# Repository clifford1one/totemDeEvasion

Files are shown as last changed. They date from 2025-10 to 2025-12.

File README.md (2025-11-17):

# totemDeEvasion

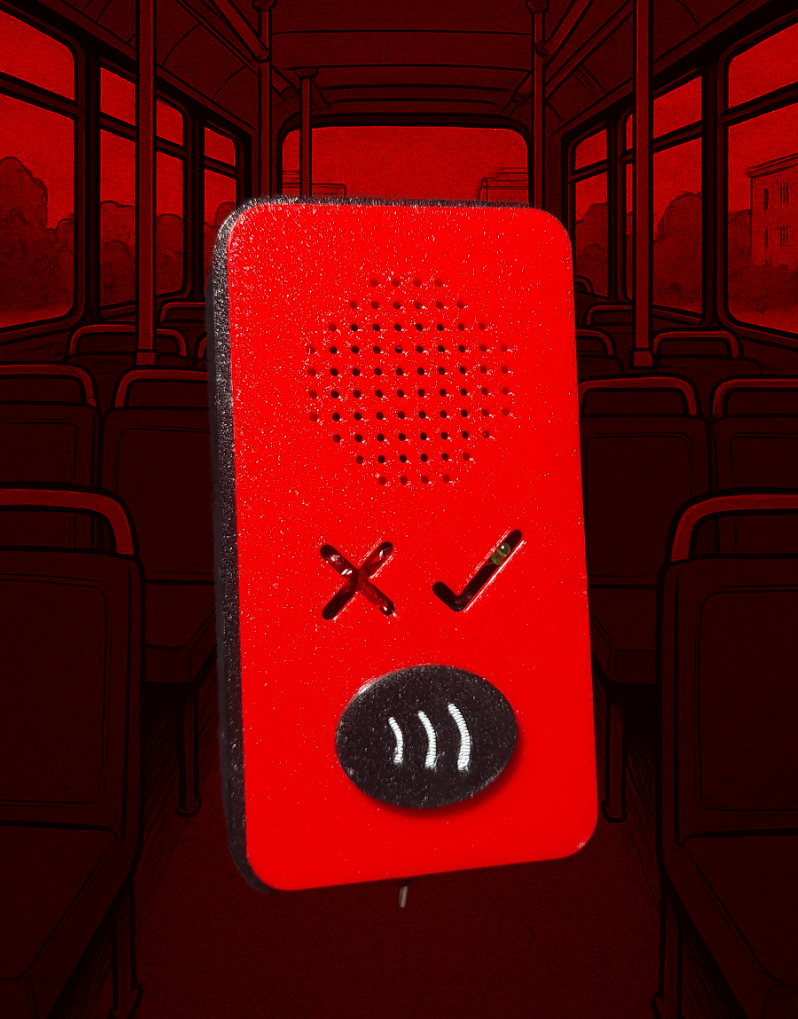
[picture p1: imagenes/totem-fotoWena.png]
imagen de presentación del totem


proyecto diseñado y fabricado por santiagoClifford en el marco de Halloween 2025. Consiste en la personificación de un ente imaginario, que representa el proceso de pagar el pasaje al subirse a las micros del sistema red.

## especificaciones

### Bill of Materials

|  | nombre | cantidad | lin compra | precio unidad(CLP) | precio item |
|---|---|---|---|---|---|
| interruptor | MTS-102 | 1 | https://afel.cl/products/interruptor-mts-102-3-pines | $400 | $400 |
| parlante | Mini Parlante Altavoz | 1 | https://afel.cl/products/mini-parlante-altavoz-de-3w | $3.000 | $3.000 |
| modulo mp3 | DFPlayer mini | 1 | https://afel.cl/products/modulo-reproductor-mp3-dfplayer-mini | $2.990 | $2.990 |
| micro sd | micro SD 16gb  | 1 | https://lapizlopez.cl/product/tarjeta-micro-sd-16gb-sdhc-cl10/ | $5.990 | $5.990 |
| lector NFC | RFID RC522 | 1 | https://afel.cl/products/lector-rfid-rc522 | $3.990 | $3.990 |
| mini broto | Mini protoboard | 1 | https://afel.cl/products/mini-protoboard-170-puntos | $990 | $990 |
| placa arduino compatible (yo usé UNO R4 Mínima) | Arduino Nano V3.0 CH340 | 1 | https://hubot.cl/producto/arduino-nano-atmega168-3-0v/ | $4.900 | $4.900 |
| cable alimentación | tipo-C a tipo-C | 1 | https://hubot.cl/producto/cable-tipo-c-a-tipo-c-para-carga-y-transmision-de-datos-30-cm-sku-4097/ | $990 | $990 |
| cables | Macho-Hembra | 1 | https://afel.cl/products/pack-20-cables-de-conexion-macho-hembra | $1.000 | $1.000 |
| cables | cable unifiliar | 20cm | https://mcielectronics.cl/shop/product/cable-para-protoboard-gris-sparkfun-10446 | $4.990 | $132 |
| led rojo | diodo led 5mm  | 2 | https://afel.cl/products/diodo-led-5mm-ultrabrillante-rojo | $70 | $140 |
| led verde | diodo led 5mm | 2 | https://afel.cl/products/diodo-led-5mm-ultrabrillante-verde?_pos=17&_sid=8cc70765c&_ss=r | $70 | $140 |
| filamento rojo | petg artillery | 25g | https://afel.cl/products/filamento-petg-rojo-artillery-1-75mm-1kg | $10.000 | $250 |
| filamento negro | pet-g artillery | 85g | https://afel.cl/products/filamento-petg-negro-artillery-1-75mm-1kg | $10.000 | $850 |
| cautín | MK0376 | 1 | https://www.mercadolibre.cl/cautin-tipo-lapiz-para-soldar-40-watts-makawa-mk-0376/p/MLC24329921 | $3.200 | $3.200 |
| estaño | Rollo soldadura | 2g | https://mcielectronics.cl/shop/product/rollo-soldadura-de-estano-1-0mm-30g/ | $3.000 | $200 |
| resistencias | 1k | 4 |  |  |  |
| resistencias | 10k | 1 |  |  |  |
| TOTAL |  |  |  |  |  |

### piezas impresas en 3D

| pieza | color | gramos |
|---|---|---|
| face | rojo | 24g |
| sostenNfc | rojo | 0.4g |
| midBod | negro | 50g |
| back | negro | 22g |
| spkrCap | negro | 6.2g |
| nfcCap | negro | 3g |
| lamp | negro | 2g |
| total | 2, 5 | 25g, 85g |

### cableado

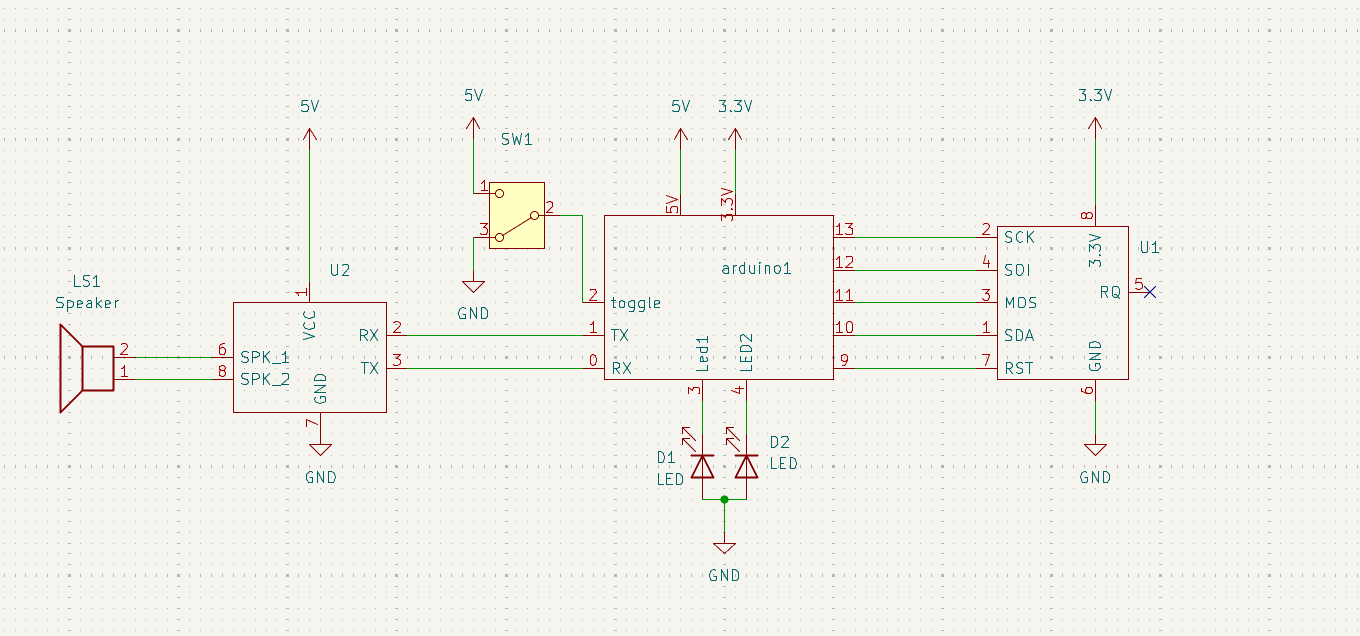
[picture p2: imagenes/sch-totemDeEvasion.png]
esquemático del cableado


esquemático hecho en kicad. Los símbolos del módulo MP3, del lector NFC y del arduino fueron hechos por mí, usando la herramienta de edición de símbolos de kicad.

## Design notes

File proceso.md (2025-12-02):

# fabricación robot y unión de partes

## proceso

este paso, viene después de entender el funcionaiento, por separado, del sensor nfc, y el toggle. 

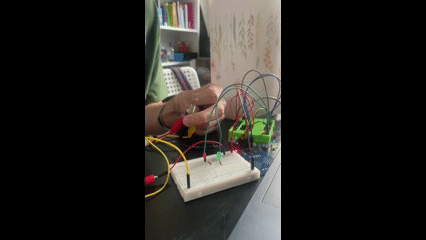
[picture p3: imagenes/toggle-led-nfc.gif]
gif del funcionamiento


armé el circuito para que, cuanod se sense un nfc, se mande un output de una LED, este output varía según el estado del toggle.

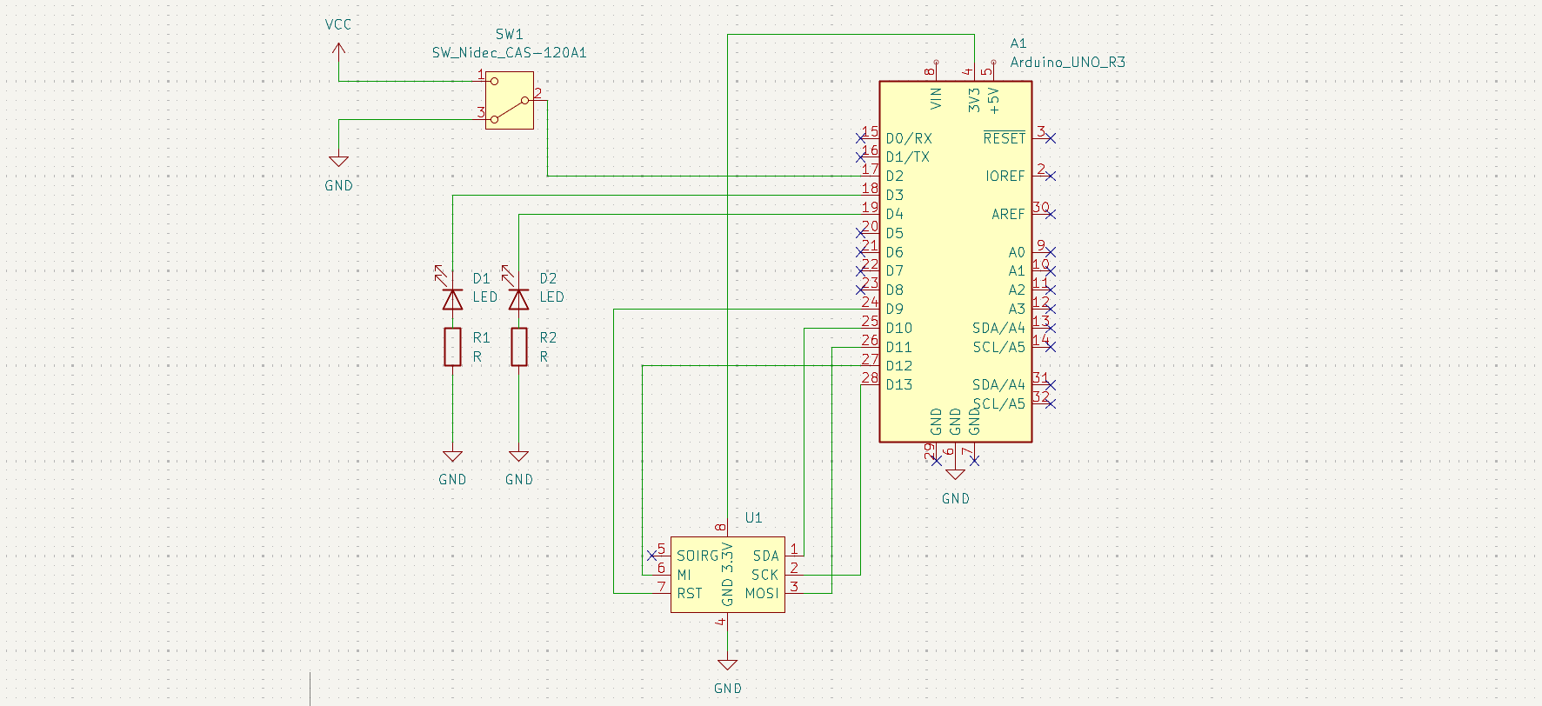
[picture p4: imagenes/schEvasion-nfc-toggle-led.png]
esquemático del circuito hasta ahora


ahí se ve un esquemático de cómo se ve hasta ahora.

## rfid

### sensor nfc

<https://naylampmechatronics.com/blog/22_tutorial-modulo-lector-rfid-rc522.html>

con ese tutorial, pude detectar las ID de los nfc, y lo reduje para que imprima en el puerto serial "detectado" cada vez que sensa un nfc.

```cpp
#include <SPI.h>
#include <MFRC522.h>

#define RST_PIN 9
#define SS_PIN 10
MFRC522 mfrc522(SS_PIN, RST_PIN);

void setup() {
  Serial.begin(9600);
  SPI.begin();
  mfrc522.PCD_Init();
}

void loop() {
  if (mfrc522.PICC_IsNewCardPresent() && mfrc522.PICC_ReadCardSerial()) {
    Serial.println("detectado");
    mfrc522.PICC_HaltA();
  } 
}
```

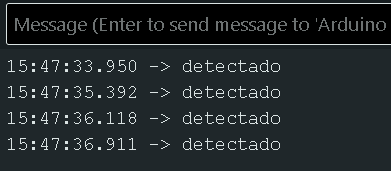
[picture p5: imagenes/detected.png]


## módulo mp3

### MP3-TF-1GP

[datasheet](https://www.alldatasheet.es/html-pdf/2032297/AGELECTRONICA/MP3-TF-16P/1185/1/MP3-TF-16P.html)

<https://www.build-electronic-circuits.com/arduino-speaker>

este módulo acpeta tarjeta micro SD de 32gb o menos. 

solo poseo una micro SD de 64Gb, compré una [Adata Premier microSDHC](https://www.myshop.cl/producto/memoria-flash-32-gb-adata-premier-microsdxcsdhc-uhs-i-class10-ausdh32guicl10a1-ra1-p38615)

cuando intenté colocar los archivos, windows me indicaba que la tarjeta tiene protección contra escritura. Finalmente pude resolverlo usando el command prompt con [este tutorial](https://www.youtube.com/watch?v=uPSLwj0JEJI)

Los sonidos lo extraje de videos de youtube. 

el sonido que suena cuando pagas el pasaje lo saqué de [este reportaje](https://youtu.be/WrMJ976EuA4?si=CqZEK9t-8fkpy0fj)

el sonido que suena cuando el saldo es insuficiente lo saqué de [este youtube short](https://youtu.be/vTpdEQijg0s?si=Jww4EK1SQI2xIPfD)

depués de muchos intentos fallidos, leí que con tarjetas microSD de 32gygabytes era poco estable, asi que me robé la microSD del celular de mi awela, y le puse la que había comprado de 32GB.

logre que funcionara con [este tutorial](https://wiki.dfrobot.com/DFPlayer_Mini_SKU_DFR0299#Connection_Diagram)

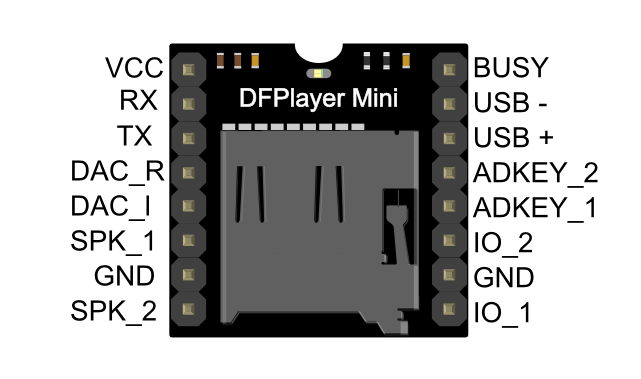
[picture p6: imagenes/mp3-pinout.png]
pinout del módulo


## interruptor

###### código

estas son las líneas de código necesarias para que el estado del toggle defina el output.

```cpp
int togglePin;

void setup(){
  pinMode(togglePin, INPUT);
}

void loop(){
    if (state == HIGH) {
      Serial.println("Switch ON → approved!");
    } else {
      Serial.println("Switch OFF → denied!");
    }

}
  ```

con el código anterior el puerto serial muestra lo siguiente:

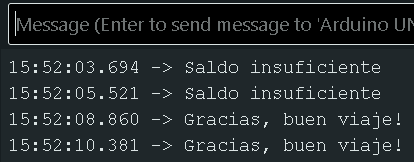
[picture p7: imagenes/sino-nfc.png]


##### pinout

El cableado del toggle, es el común a un pin digital, y los pines de los lados uno a GND y otro a 5V.

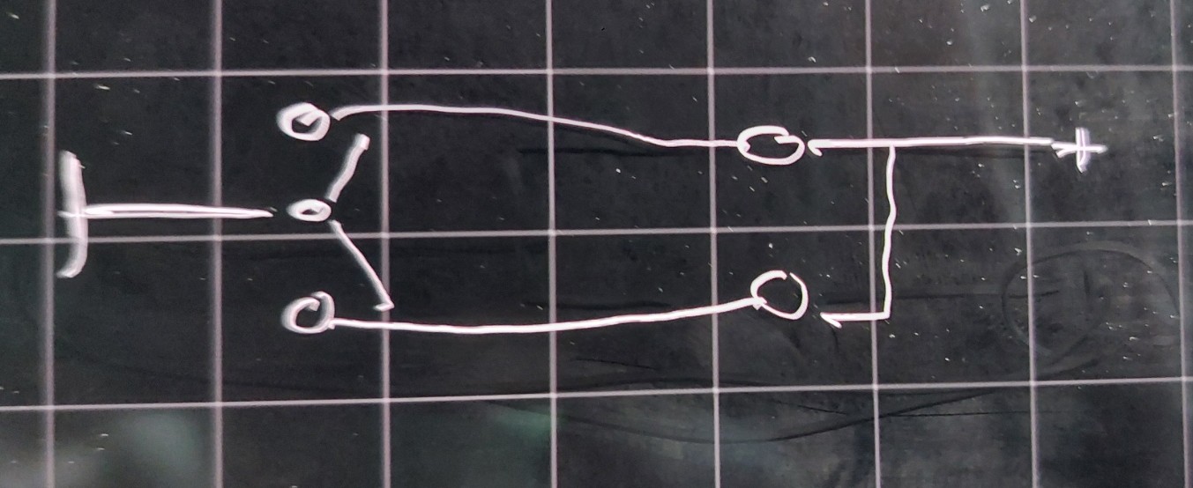
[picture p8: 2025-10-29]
imagenes/sch-toggle.jpg

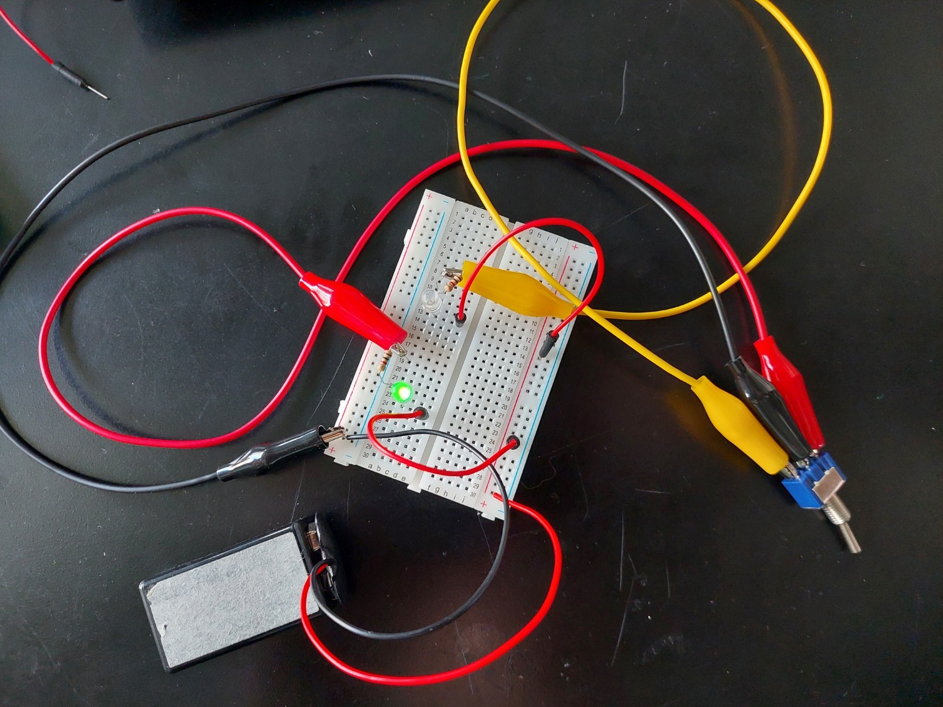
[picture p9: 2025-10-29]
imagenes/circuito-toggle.jpg

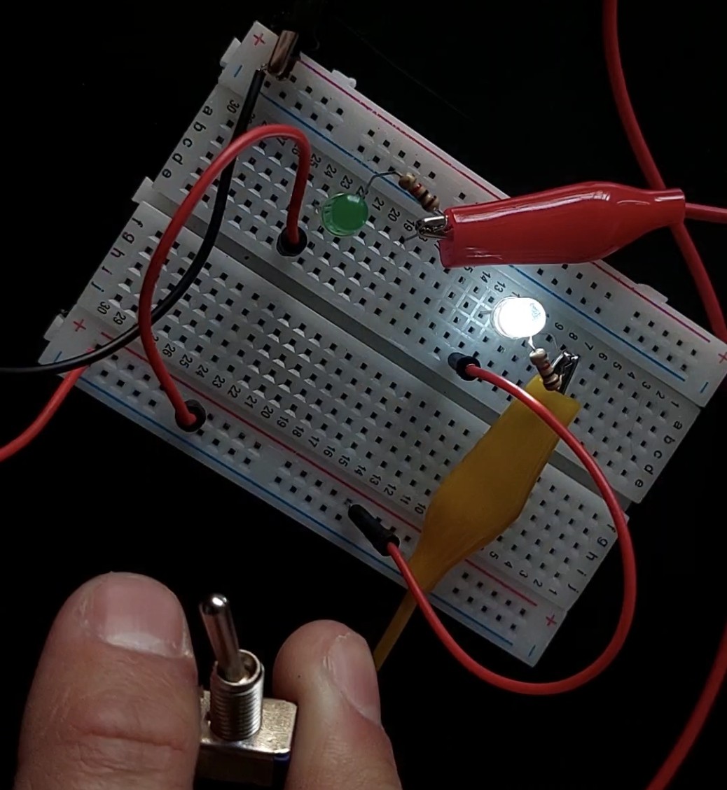
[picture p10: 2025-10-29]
imagenes/toggle-led1.jpg

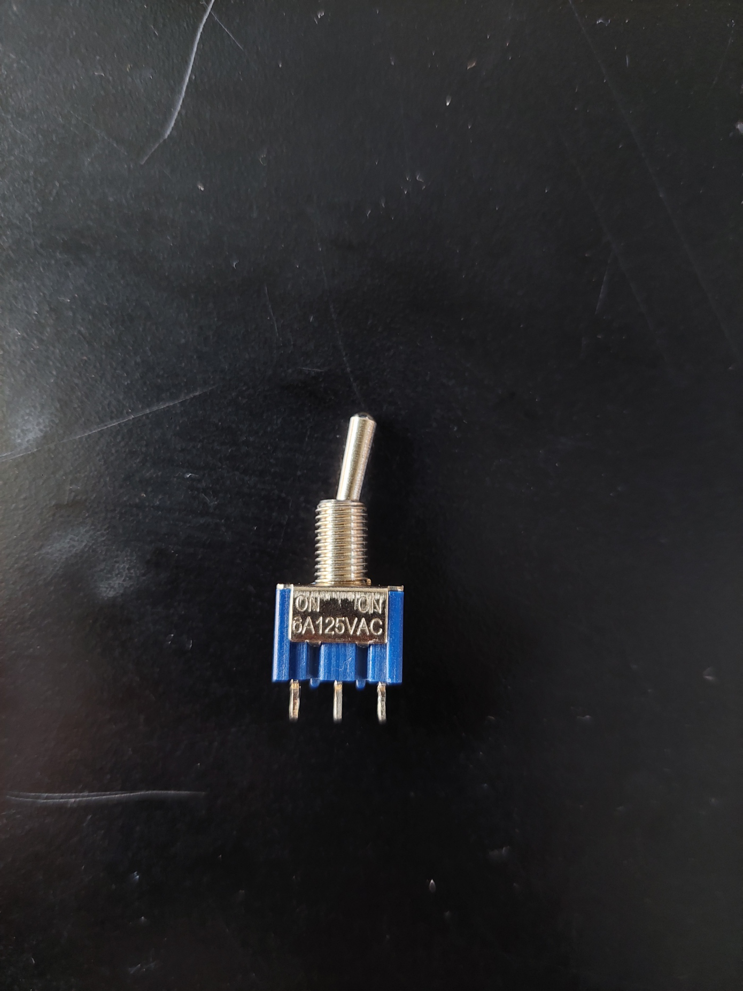
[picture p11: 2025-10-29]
imagenes/toggle.jpg

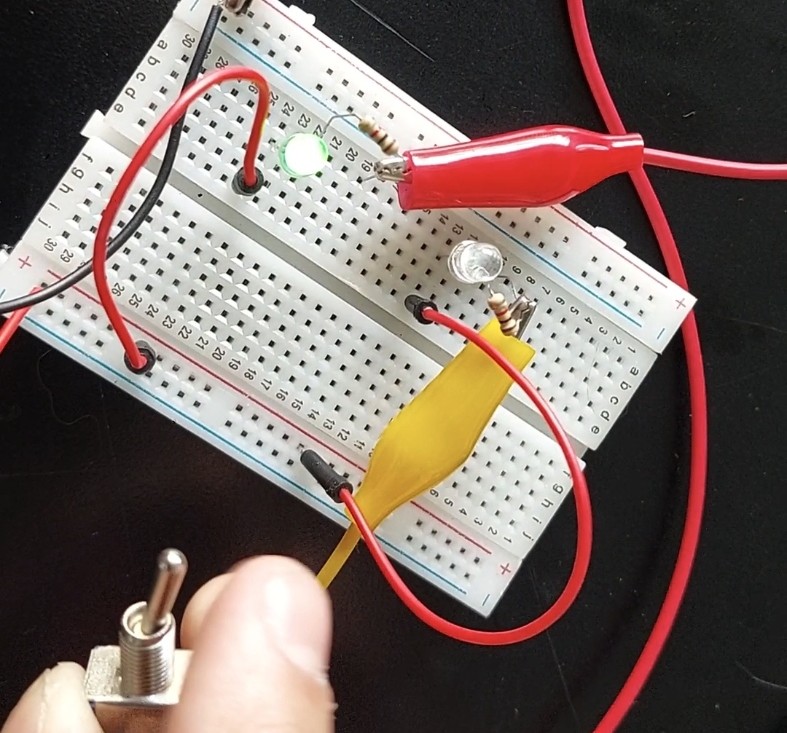
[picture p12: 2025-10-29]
imagenes/toggle-led2.jpg

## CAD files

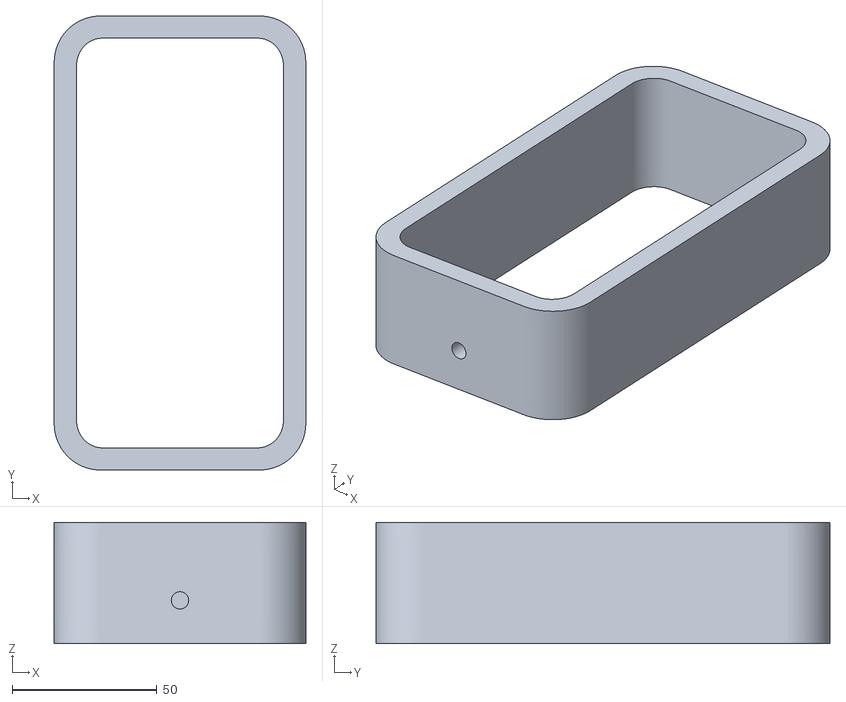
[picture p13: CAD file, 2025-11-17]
modelosReduced/midBod.stl
87.0 x 157.0 x 42.0

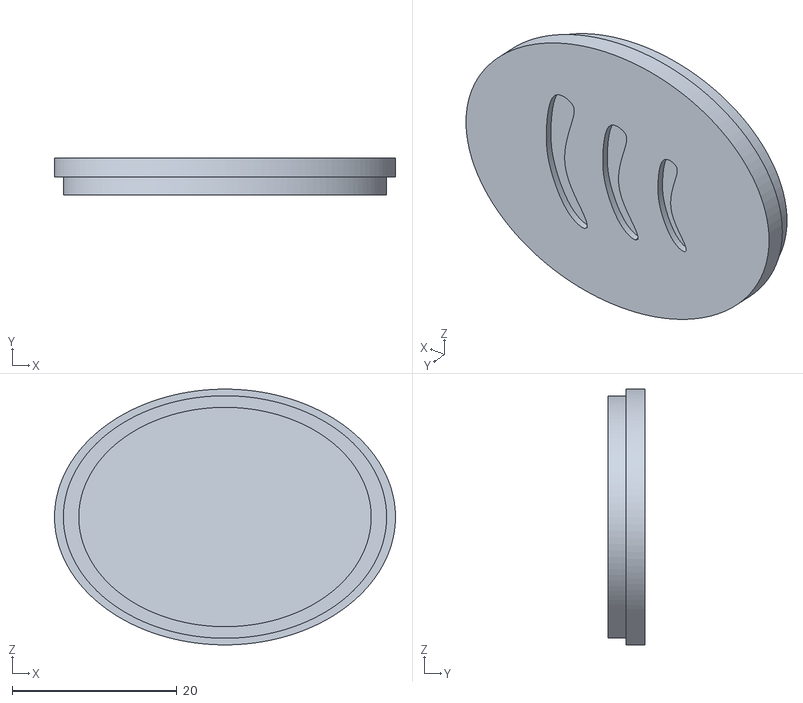
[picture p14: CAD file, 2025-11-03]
modelosReduced/nfc-cap.stl
41.4 x 4.52 x 31.1

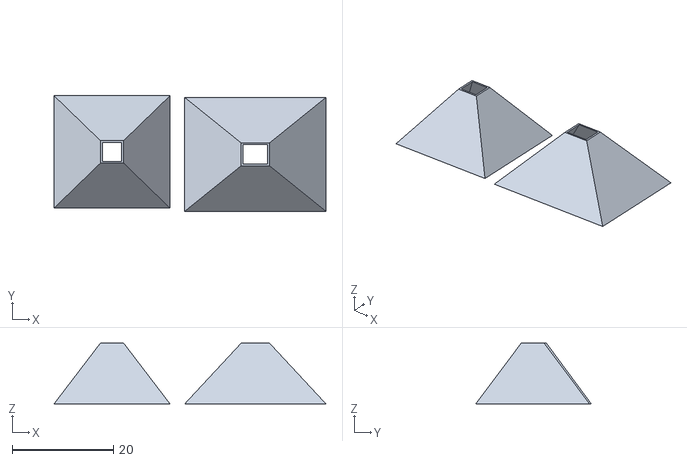
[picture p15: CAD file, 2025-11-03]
modelosReduced/lamps.stl
53.7 x 22.8 x 12.0

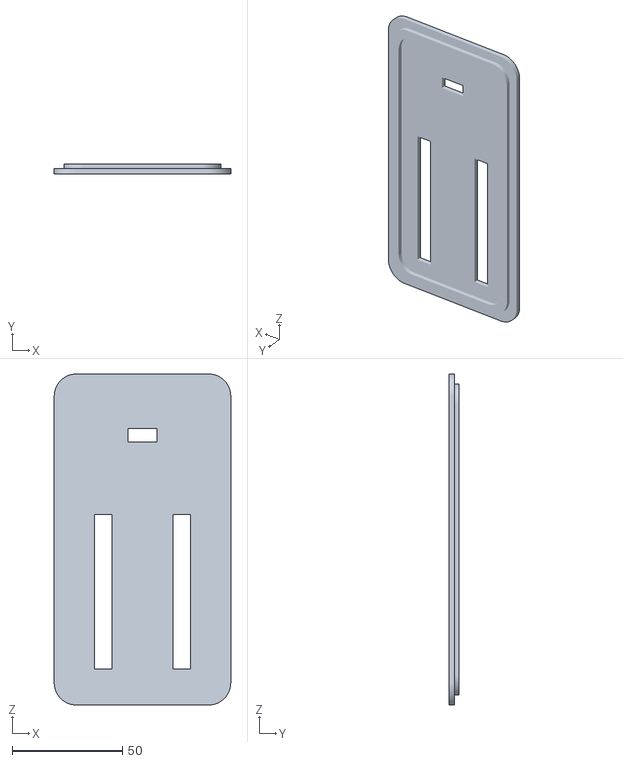
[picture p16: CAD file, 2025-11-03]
modelosReduced/backBod.stl
80.0 x 4.50 x 150.0

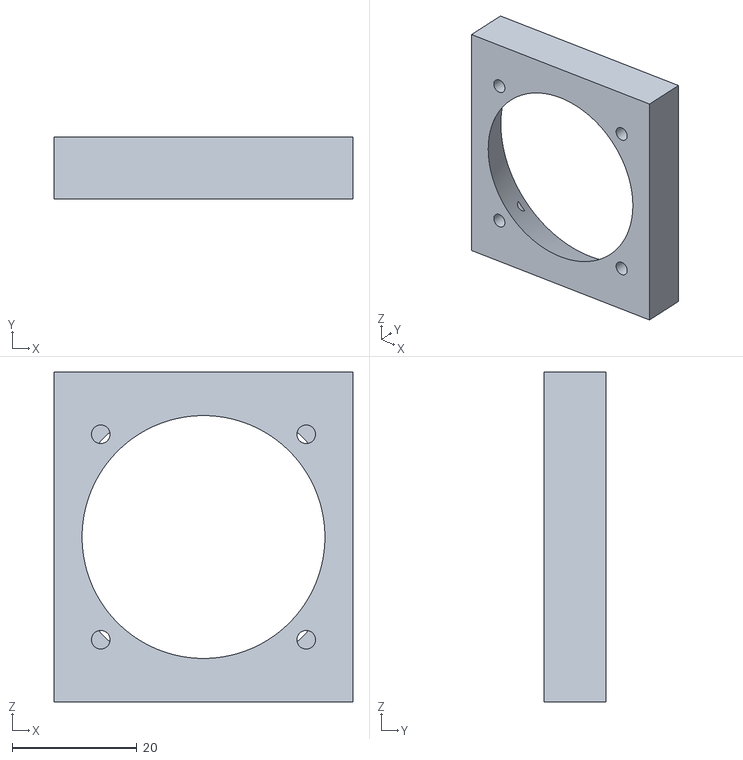
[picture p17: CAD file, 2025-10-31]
modelosReduced/spkr-cap.stl
48.0 x 10.0 x 53.0

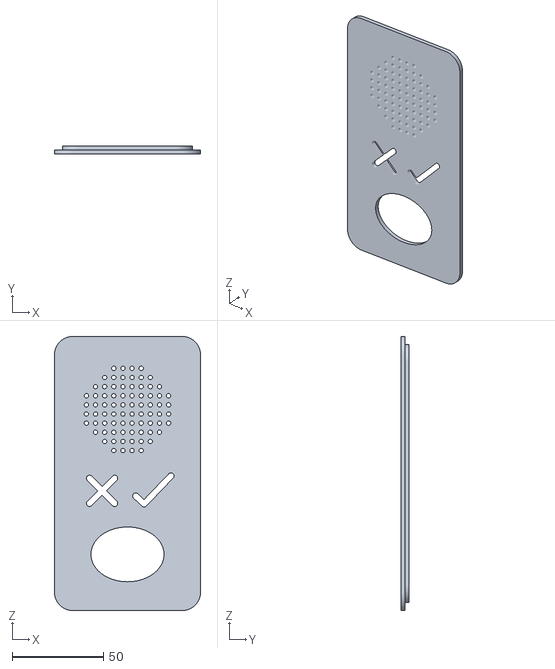
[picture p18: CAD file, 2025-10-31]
modelosReduced/faceBod.stl
80.0 x 4.54 x 150.0

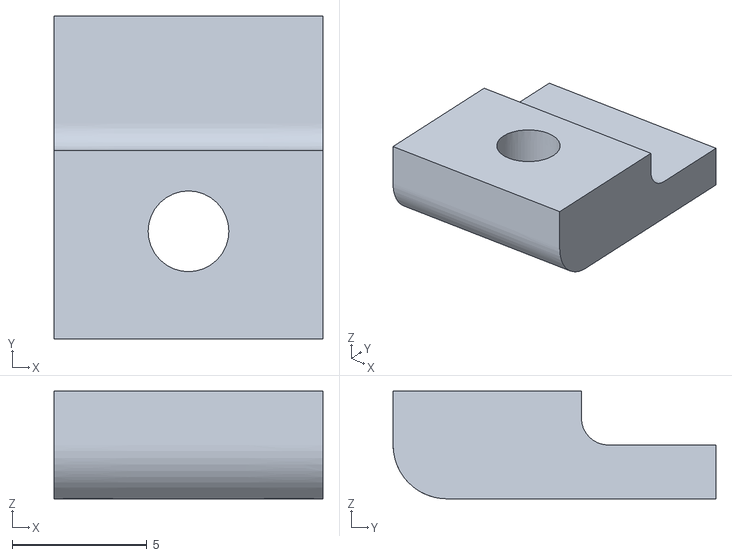
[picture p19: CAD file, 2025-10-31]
modelosReduced/nfc-sosten.stl
10.0 x 12.0 x 4.00

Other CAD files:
modelos/componentes.3dm

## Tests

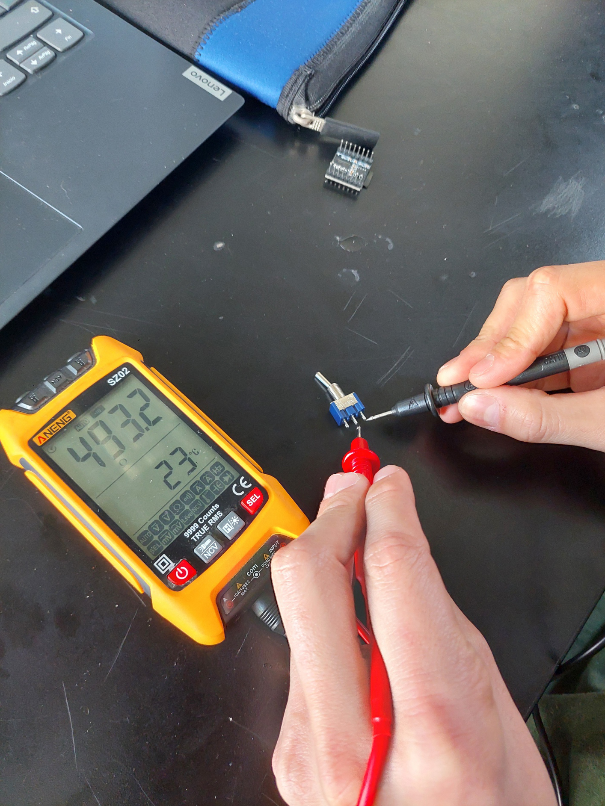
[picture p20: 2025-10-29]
imagenes/toggle-tester.jpg

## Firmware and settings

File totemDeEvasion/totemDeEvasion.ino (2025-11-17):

/////////////////////////////////////////////////////////////
/*este es un código hecho por santiagoClifford para el 
proyecto totemDeEvasion. Este codigo controla un dispositivo
que recrea la experiencia de pagar la micro en la vida real.

Este dispositivo reacciona frente a nfc, y a traves de
un parlante y varios led, le informa al usuarie si tiene
saldo o no. Esto dependerá del estado de un interruptor.*/
/////////////////////////////////////////////////////////////


#include "Arduino.h"
#include "DFRobotDFPlayerMini.h"
//audio
#include <SPI.h>
#include <MFRC522.h>

//variables audio
const int paseAdelante = 1;
const int saldoInsuficiente = 2;
const int delayLed = 1800;

//pines lector nfc
const int resetPin = 9;
const int ssPin = 10;

//otros pines
int pinToggle = 2;
int pinLedRojo = 3;
int pinLedVerde = 4;

//intancia del lector nfc
MFRC522 mfrc522(ssPin, resetPin);

//configuracion de comunicación serial del modulo mp3
#if (defined(ARDUINO_AVR_UNO) || defined(ESP8266))
#include <SoftwareSerial.h>
SoftwareSerial softSerial(10, 11);
#define FPSerial softSerial
#else
#define FPSerial Serial1
#endif

//intancia mp3
DFRobotDFPlayerMini myDFPlayer;

void setup() {
  Serial.begin(115200);

  //inicialiazación lector nfc
  SPI.begin();
  mfrc522.PCD_Init();

  //config pines
  pinMode(pinToggle, INPUT);
  pinMode(pinLedRojo, OUTPUT);
  pinMode(pinLedVerde, OUTPUT);

  //inicialización audio
  FPSerial.begin(9600);


  if (!myDFPlayer.begin(FPSerial, true, true)) {
    Serial.println("Error: Revisar conexion y tarjeta SD");
    while (true) delay(0);
  }
}

void loop() {
  //aqui se setea el lector nfc para que este verifique si se detecta un nfc
  if (mfrc522.PICC_IsNewCardPresent() && mfrc522.PICC_ReadCardSerial()) {

    //leer el estado del toggle(interruptor)
    int state = digitalRead(pinToggle);

    //esta es la condición de con saldo/sin saldo
    if (state == HIGH) {
      //SI TIENES SALDO
      myDFPlayer.play(paseAdelante);
      digitalWrite(pinLedVerde, HIGH);
      Serial.println("ADELANTE PASE");
      delay(delayLed);
      digitalWrite(pinLedVerde, LOW);


    } else {
      //SI NO TIENES SALDO
      myDFPlayer.play(saldoInsuficiente);
      digitalWrite(pinLedRojo, HIGH);
      Serial.println("Saldo insuficiente");
      delay(delayLed);
      digitalWrite(pinLedRojo, LOW);
    }
    //detener com lector nfc
    mfrc522.PICC_HaltA();
  }
}

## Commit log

2025-10-29 avamce de hoy uwu
2025-10-30 avance compoentnes 3dm
    [componentes.3dm]
2025-11-17 avance capo y ordenado
    [back.stl, backBod.stl, face.stl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]
